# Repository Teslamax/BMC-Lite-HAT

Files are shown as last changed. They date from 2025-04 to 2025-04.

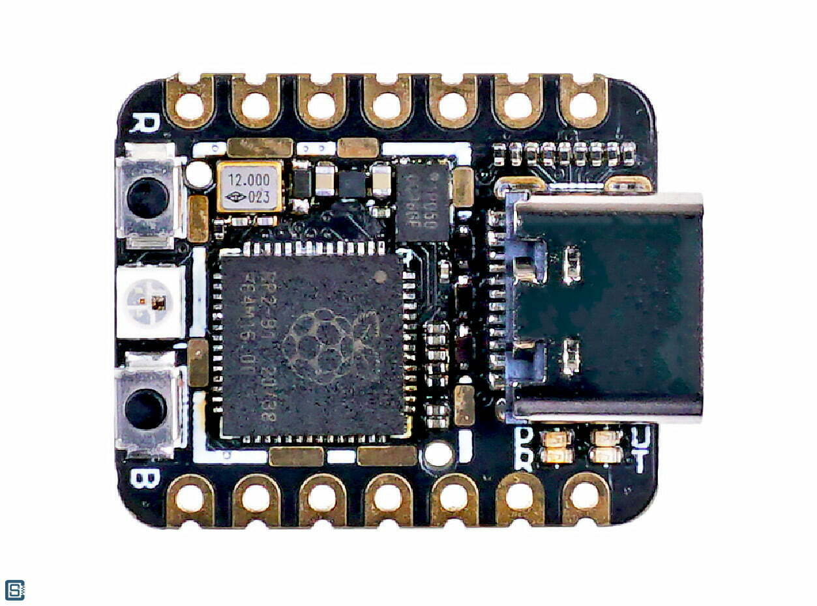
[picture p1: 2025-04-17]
hardware/XIAO RP2040/Seeedstudio-Seeeduino-XIAO-RP2040-Microcontroller-Board-PCB-Top-Shielding-Removed-1.jpg

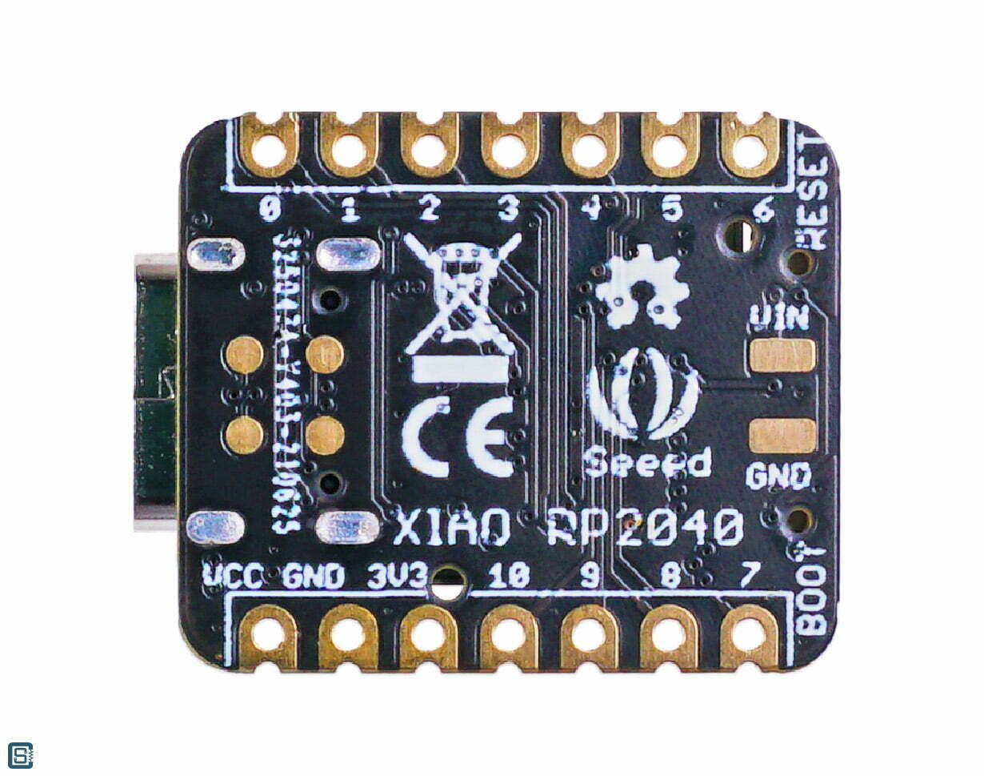
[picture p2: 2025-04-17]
hardware/XIAO RP2040/Seeedstudio-Seeeduino-XIAO-RP2040-Microcontroller-Board-PCB-Bottom-1.jpg

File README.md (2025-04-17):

# BMC-Lite HAT

A minimalist Raspberry Pi companion board that provides **safe power control**, **status indication**, and **serial console monitoring** for headless systems like the Pi Zero and Pi Zero 2.

BMC-Lite behaves like a simplified BMC (Baseboard Management Controller), using a microcontroller (e.g. XIAO RP2040) to coordinate shutdown, reboot, user-defined input, and status feedback — all with minimal Pi-side dependencies.

---

## ✨ Key Features

- 🧠 Clean shutdown, reboot, and optional user-defined buttons
- 🌈 RGB LED for system status (boot, running, halted, panic, etc.)
- 🔁 Bidirectional UART between Pi and MCU for serial console parsing
- 🫀 Heartbeat monitoring via `gpio-led` overlay on Pi GPIO6
- 🔌 Power-safe operation using Schottky diodes (no USB backfeed)
- 📟 Optional I²C OLED display (address `0x3C`)
- 📦 Compact Pi Zero-compatible form factor

---

## 🔩 Hardware Overview

- Microcontroller: **Seeed XIAO RP2040**
- Communication:
  - **UART** (Pi `GPIO14/15`) for console output / command reception
  - **GPIO overlays** for poweroff, shutdown, reboot
  - **I²C** (shared bus for OLED + optional MCP23017 expander)
- RGB LED: onboard XIAO NeoPixel used for state indication
- Buttons: physical momentary buttons (shutdown, reboot, user-defined)
- Power: 5V input from Pi via Schottky diode OR USB-C (dev mode)

> See [`OVERVIEW.md`](OVERVIEW.md) for detailed power modes and deployment strategy.

---

## ⚙️ Raspberry Pi Configuration

Add the following to your `/boot/config.txt`:

```ini
# Enable UART (optional but recommended)
enable_uart=1

# GPIO overlays
dtoverlay=gpio-shutdown,gpio_pin=22,active_low=1,gpio_pull=up
dtoverlay=gpio-poweroff,gpiopin=26,active_low=0
dtoverlay=gpio-restart,gpio_pin=27,active_low=1

# Heartbeat overlay (blinks GPIO6 at ~1Hz)
dtoverlay=gpio-led,gpio=6,trigger=heartbeat
```

> Note: Overlay pins can be adjusted if your board is wired differently — see [`docs/PINOUT.md`](docs/PINOUT.md).

---

## 🌈 RGB LED Status

| State | Color | Pattern | Meaning |
|---|---|---|---|
| Off | ⚫ Off | Off | No Pi power |
| Booting | 🟠 Orange  | Breathing | Pi serial console detected |
| Running | 🟢 Green | Solid | Heartbeat detected |
| Shutting Down | 🟡 Yellow  | Slow Blink | Shutdown in progress |
| Halted | 🔴 Red | Solid | GPIO26 HIGH — safe to power off  |
| Crash / Panic | 🟣 Magenta | Fast Blink | Kernel panic (detected via UART) |
| Unresponsive | 🟤 Amber | 2s Blink | Heartbeat timeout |

> A copy of this table also exists in the docs, alongside state machine definitions and implementation.

---

## 🧭 Pin Mapping

See [`docs/PINOUT.md`](docs/PINOUT.md) for the authoritative pin allocation between:

- Raspberry Pi GPIO
- XIAO RP2040
- Optional MCP23017 I/O Expander

---

## 📄 License

MIT or CC-BY 4.0 — TBD

---

## 💬 Credits

Designed by [You], with architectural support from ChatGPT.  
Inspired by system BMCs, IPMI, `systemd`, and the belief that small devices deserve great UX too.

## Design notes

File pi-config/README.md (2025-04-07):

# Raspberry Pi Setup Guide for BMC-Lite-HAT

This guide walks you through setting up your Raspberry Pi to work with the BMC-Lite HAT using GPIO overlays, UART, and the optional heartbeat monitoring service.

---

## 🧰 Files Included

- `config.txt.snippet`: Additions to your Pi's `/boot/config.txt`
- `cmdline.txt.snippet`: Serial console enable line for `/boot/cmdline.txt`
- `heartbeat.py`: Python script to toggle a GPIO as a heartbeat signal
- `heartbeat.service`: systemd unit file to run `heartbeat.py` at boot

---

## ⚙️ Step-by-Step Setup

### 1. Enable UART and Overlays

Edit your `/boot/config.txt`:

```bash
sudo nano /boot/config.txt
```

Append the following (or copy from `config.txt.snippet`):

```ini
enable_uart=1
dtoverlay=gpio-shutdown,gpio_pin=22,active_low=1,gpio_pull=up
dtoverlay=gpio-poweroff,gpiopin=26,active_low=0
dtoverlay=gpio-restart,gpio_pin=27,active_low=1
```

### 2. Enable Serial Console Output

Edit `/boot/cmdline.txt` (this file is a **single line**!):

```bash
sudo nano /boot/cmdline.txt
```

Add this to the end (if not present):

```
console=serial0,115200
```

> ⚠️ Do not break the line into multiple lines.

---

### 3. Install Heartbeat Service (Optional)

#### Copy files to their locations:

```bash
sudo cp pi-config/heartbeat/heartbeat.py /usr/local/bin/
sudo chmod +x /usr/local/bin/heartbeat.py
```

```bash
sudo cp pi-config/heartbeat/heartbeat.service /etc/systemd/system/
```

#### Enable the service:

```bash
sudo systemctl daemon-reexec
sudo systemctl enable heartbeat.service
sudo systemctl start heartbeat.service
```

To check status:

```bash
sudo systemctl status heartbeat.service
```

---

## 🔁 Reboot

After all steps are complete:

```bash
sudo reboot
```

Your Raspberry Pi should now:
- Output logs via UART
- Respond to shutdown/restart GPIOs
- Pulse GPIO17 as a heartbeat indicator

---

## ✅ Summary

- UART and overlays allow microcontroller monitoring and control
- Heartbeat helps detect unresponsive Pi
- No kernel modules or packages are required — just Python and systemd

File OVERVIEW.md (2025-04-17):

# BMC-Lite HAT – System Overview

BMC-Lite HAT is a compact Raspberry Pi companion board designed to provide basic BMC-like functionality such as controlled shutdown, reboot, user input, and visual feedback for headless systems.

Built around the Seeed XIAO RP2040, it integrates clean power handling, GPIO signaling, and serial monitoring in a Pi Zero-sized footprint.

## ✅ Key Capabilities

- Clean shutdown, reboot, and user interaction via physical buttons
- Visual feedback through onboard RGB LED (NeoPixel)
- Safe power sharing between Pi and USB using Schottky diodes
- DEV vs RUN mode switch for debugging vs deployment
- UART-based serial monitoring
- Optional I²C OLED and GPIO expander (MCP23017)

## 🔋 Power Notes

The XIAO RP2040 can be safely powered from either:

- The Raspberry Pi's 5V rail via an **external Schottky diode**
- Its onboard USB-C connection (protected by a built-in Schottky diode)

This allows safe simultaneous connection of both USB and Pi power without a physical DEV/RUN switch.
## 🔋 Power Architecture

- `V_SYS` rail is shared between Pi 5V (via diode) and USB-C
- XIAO VBUS (Pin 14) connects to V_SYS in RUN mode
- Schottky diodes prevent reverse current into Pi or USB host
## 🫀 Heartbeat Monitoring

To indicate the Pi is alive:

Add to `/boot/config.txt`:
```ini
dtoverlay=gpio-led,gpio=6,trigger=heartbeat
```

- Uses **GPIO6 (Pin 31)** to pulse at ~1Hz
- Connect to **XIAO GPIO10** or MCP23017 GPIO for monitoring
## 📦 Physical & Logical Summary

- Board form factor: pHAT (fits Pi Zero footprint)
- GPIO header: stacking or through-hole
- Optional 4-pin OLED header (`0x3C`)
- Optional MCP23017 I/O expander (`0x20`)

For detailed wiring, see [`docs/PINOUT.md`](docs/PINOUT.md)

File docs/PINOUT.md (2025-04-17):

# BMC-Lite HAT Pin Mapping

## 🔌 XIAO RP2040 GPIO Assignments

| GPIO | Pin | Function | Direction | Connected To | Notes |
|---|-----|---|---|---|---|
| 26 | 1 | `INT` from Expander | Input | *MCP23017* `INTA` Pin | INT fires on button state changes  |
| 27 | 2 | Free (`ADC1`) | — | — | General-purpose |
| 28 | 3 | Free (`ADC2`) | — | — | ADC-capable input |
| 29 | 4 | Free (`ADC3`) | — | — | ADC-capable input |
| 6 | 5 | I²C `SDA` | Bidirectional | OLED, GPIO Expander | Addr `0x3C` (OLED), `0x20` (MCP) |
| 7 | 6 | I²C `SCL` | Bidirectional | OLED, GPIO Expander | Shared I²C bus |
| 0 | 7 | UART `TX` | XIAO → Pi | Pi `GPIO15` (Pin 10)  | UART console |
| 1 | 8 | UART `RX` | Pi → XIAO | Pi `GPIO14` (Pin 8) | UART console |
| 2 | 9 | Free (`SPI`-`SCK`)  | — | — | — |
| 4 | 10  | `HEARTBEAT` | Input | Pi `GPIO6` (Pin 31) | `dtoverlay`-driven 1Hz pulse |
| 3 | 11  | Free (`SPI`-`MOSI`) | — | — | — |
| — | 12  | `3V3` | — | — | — |
| — | 13  | `GND` | — | — | — |
| — | 14  | `VBUS` | — | — | — |

---

## 🔌 MCP23017 GPIO Expander (Prototyping Phase) (I²C addr `0x20`)

| Bank | Pin| Function | Direction | Connected To | Notes |
|---|----|---|---|---|---|
| `GPB0` | 1  |  |  |  |  |
| `GPB1` | 2  |  |  |  |  |
| `GPB2` | 3  |  |  |  |  |
| `GPB3` | 4  |  |  |  |  |
| `GPB4` | 5  |  |  |  |  |
| `GPB5` | 6  |  |  |  |  |
| `GPB6` | 7  |  |  |  |  |
| `GPB7` | 8  |  |  |  |  |
| `VDD`  | 9  |  |  |  |  |
| `VSS`  | 10 |  |  |  |  |
| — | 11 |  |  |  |  |
| `SCL`  | 12 | I²C `SCL` | Bidirectional  |  XIAO `SCL` | Shared I²C bus |
| `SDA`  | 13 | I²C `SDA` | Bidirectional  |  XIAO `SDA` | Shared I²C bus |
| — | 14 |  |  |  |  |
| `A0` | 15 |  |  |  |  |
| `A1` | 16 |  |  |  |  |
| `A2` | 17 |  |  |  |  |
| `RST`  | 18 |  |  |  |  |
| `INTB` | 19 |  |  |  |  |
| `INTA` | 20 | Interrupt | Output | XIAO `GPIO26` (Pin 1) |  |
| `GPA0` | 21 | Shutdown button | Input | Shutdown button | Debounced in software  |
| `GPA1` | 22 | Reboot button | Input | Reboot button | Debounced in software  |
| `GPA2` | 23 | User button | Input | User button | Debounced in software  |
| `GPA3` | 24 | Poweroff-Ready | Input | | |
| `GPA4` | 25 | Signal safe halt | XIAO → Pi | Pi `GPIO17` | Logic state  |
| `GPA5` | 26 | Signal safe reboot | XIAO → Pi | Pi `GPIO27` | Logic state  |
| `GPA6` | 27 | Signal user-defined  | XIAO → Pi | Pi `GPIO22` | Logic state  |
| `GPA7` | 28 | Unused | — | — | Reserved for expansion |
| `GPB*` | —  | Unused | — | — | Reserved for expansion |

---

## 🔌 Raspberry Pi GPIO Assignments

| Pi GPIO | Pin | Function | Direction | Connected To | Notes |
|---|-----|---|---|---|---|
| 2 | 4 | 5V Power | Output | XIAO `VBUS` via diode | — |
| 14 | 8 | UART `TX` | Output | XIAO `RX` (`GPIO1`) | Serial console |
| 15 | 10  | UART `RX` | Input | XIAO `TX` (`GPIO0`) | Serial console |
| 17 | 11  | Shutdown Trigger | Input | Expander | `dtoverlay=gpio-shutdown` |
| 27 | 13  | Reboot Trigger | Input | Expander | `dtoverlay=gpio-restart` |
| 22 | 15  | User-defined Input | Input | Expander | Optional override or trigger |
| 5 | 29  | Poweroff-Ready | Output | Expander | High when safe to power off |
| 6 | 31  | `HEARTBEAT` | Output | XIAO `GPIO10` | dtoverlay: gpio-led trigger |

---

## 🔋 Power & Ground

| Signal | Pi Pin(s) | XIAO Pin | Notes |
|---|---|---|---|
| 5V | 2 or 4 | 14 (`VBUS`) | Via Schottky, dual-source capable — switch isolation no longer required |
| `GND`  | 6, 9, etc | 13 (`GND`)  | Shared ground reference |

> ⚠️ **Note on `VBUS` and Power Safety:**
>
> The XIAO RP2040 includes an internal Schottky diode between its USB-C VBUS input and Pin 14 (`VBUS`). This prevents backfeed from external 5V sources (like the Pi) into the USB port. When combined with an external Schottky diode protecting the Pi's 5V rail, this configuration allows safe, simultaneous connection of both USB-C and Pi 5V power **without requiring a physical DEV/RUN switch**. The XIAO RP2040 does not include a VBAT or battery charging circuit, so Seeed Studio's general battery safety warnings do not apply here.

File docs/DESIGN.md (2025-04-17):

# BMC-Lite HAT – Design Overview

**BMC-Lite HAT** is a compact, low-cost control and status interface board for headless Raspberry Pi systems.  
It provides **safe shutdown and reboot control**, **user input**, **status indication**, and **power protection**, while enabling easy prototyping and future expandability.

---

## 🎯 Project Goals

- Allow clean shutdown and reboot of headless Raspberry Pi devices
- Support up to 3 debounced physical buttons (shutdown, reboot, user)
- Monitor Pi health via UART and a heartbeat GPIO
- Provide visual feedback using the XIAO's onboard RGB LED and optional I²C OLED
- Maintain power separation and protection between the Pi and USB
- Fit entirely on a solderless breadboard for early prototyping

---

## 🧱 Hardware Overview

### MCU: **Seeed XIAO RP2040**

- Handles button input with debouncing
- Sends shutdown and reboot signals to the Pi
- Receives Pi "ready for poweroff" and "heartbeat" signals
- Optionally monitors UART output from Pi
- Drives an optional I²C OLED
- Uses all **12 GPIOs** on the XIAO

### Raspberry Pi

- Uses `dtoverlay`-based GPIO triggers
- Powered independently (no USB power sharing)
- Communicates with XIAO via GPIO and UART
- Provides power to XIAO (with diode protection)

---

## ⚡ Dual-Power Protection: Discrete Schottky Diodes

### Purpose:
Prevent power contention between **USB (VBUS)** and **Pi 3.3V rail** by OR-ing both into a common `V_SYS` rail.

### Materials:
- 1x discrete Schottky diodes (e.g., 1N5817, BAT85) (one is already protecting the USB-C 5v source on the XIAO-RP2040)
- 1x 10–47µF ceramic capacitor (0805/1206, X5R or X7R)

### Diagram:

```text
Pi 3.3V ───┬────|<|──┐
           │         │
           │         ├───► V_SYS ──► XIAO 3.3V (Pin 13)
USB 3.3V ──┴────|<|──┘
                 │
              [Capacitor]
                 │
                GND

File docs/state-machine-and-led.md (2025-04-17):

# BMC-Lite HAT – System State Machine and LED Status

This document defines the internal firmware state machine of the BMC-Lite HAT and its corresponding RGB LED feedback patterns. Together, these mechanisms enable real-time monitoring and intuitive diagnostics for headless Raspberry Pi systems.

---

## 🌈 LED Status Mapping

| State | Color | Behavior | Meaning |
|---|---|---|---|
| Off | ⚫ Off | Off | No Pi power |
| Booting | 🟠 Orange | Breathing | Parsing serial boot logs |
| Running | 🟢 Green | Solid | Heartbeat OK |
| Shutting Down | 🟡 Yellow | Slow Blink | Shutdown in progress |
| Halted | 🔴 Red | Solid | GPIO26 high: safe to power off |
| Crash / Panic | 🟣 Magenta | Fast Blink | Kernel panic, log detected |
| Unresponsive | 🟤 Amber | 2s Blink | Heartbeat timeout |

---

### State Descriptions

- **OFF**: No Pi power (5V not detected)
- **BOOTING**: Serial console active, parsing boot messages
- **RUNNING**: Heartbeat GPIO detected, Pi is healthy
- **SHUTTING_DOWN**: Serial message indicates shutdown
- **UNRESPONSIVE**: Heartbeat GPIO silent (timeout)
- **CRASHED**: Kernel panic or failure detected in serial output
- **HALTED**: GPIO26 pulled HIGH via dtoverlay = safe to power off
- **OVERRIDE**: User override state, for testing or forcing modes

## 🧠 System State Machine

```mermaid
stateDiagram-v2
    [*] --> OFF
    OFF --> BOOTING : Pi 5V detected
    BOOTING --> RUNNING : boot log
    BOOTING --> CRASHED : panic log
    RUNNING --> SHUTTING_DOWN : shutdown log
    RUNNING --> UNRESPONSIVE : heartbeat timeout
    SHUTTING_DOWN --> HALTED : GPIO26 HIGH
    UNRESPONSIVE --> HALTED : GPIO26 HIGH
    CRASHED --> HALTED : GPIO26 HIGH

    OFF --> OVERRIDE : manual
    RUNNING --> OVERRIDE : manual
    OVERRIDE --> RUNNING : exit override
    OVERRIDE --> BOOTING : simulate boot

    note right of OVERRIDE
      Manual override mode
      used for testing or simulation
    end note
```

---

## 📝 Notes

- LED color mappings follow conventional metaphors (red = stop, green = go).
- LED behavior is configurable in firmware: blink rate, colors, animations.
- OVERRIDE state can manually trigger test LEDs or simulate boot/poweroff sequences.
- System transitions may also be logged via USB CDC or Telnet CLI (if enabled).

---

## 📚 Related

- [`WIRING.md`](WIRING.md) for heartbeat GPIO and LED wiring
- [`POWER.md`](POWER.md) for power detection behavior

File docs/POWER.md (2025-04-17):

# BMC-Lite HAT – Power Architecture & Safety

This document describes how power flows through the BMC-Lite HAT system and explains the use of diodes to safely support both Raspberry Pi and USB power sources.

---

## 🔋 Overview

The system is designed to allow the Raspberry Pi and USB-C to be connected at the same time without risk of damaging backfeed.

### Power Sources:
- **USB-C** → XIAO RP2040 (internal Schottky protection)
- **Raspberry Pi 5V GPIO (Pin 2 or 4)** → external Schottky diode → XIAO VIN

Both sources feed into a common `V_SYS` rail safely.

---

## 🔌 Diode-Based Protection

### XIAO RP2040 (Built-in):
- Includes a **Schottky diode** from USB-C to VBUS (Pin 14)
- Prevents backfeed from Pi into USB host

### Raspberry Pi to XIAO (External):
- A **1N5819** or similar diode is placed between the Pi’s 5V rail and the XIAO’s VBUS
- Prevents USB power from backfeeding into the Pi

---

## 🔄 Power Flow Diagram (Textual)

```
[Pi 5V GPIO] --|>|--+
               D1   |
                   [ V_SYS Rail ] --- XIAO VBUS (Pin 14)
[USB-C] --------|>|--+
               (internal)
```

> **D1**: External Schottky diode (e.g., 1N5817, SS14, BAT54)

---

## ✅ Safe Use Cases

| Power Scenario | Safe? | Notes |
|---|---|---|
| Only Pi connected (no USB) | ✅ | Pi powers XIAO through D1 |
| Only USB connected | ✅ | USB powers XIAO via internal diode |
| Both connected | ✅ | Each input is isolated; no current conflict  |

---

## ⚠️ Best Practices

- Use **low forward-voltage Schottky diodes** for efficient power transfer
- Place a **47–100 µF capacitor** near VIN and GND to smooth transitions
- No need for a physical switch — diode logic handles source selection

---

## 🧪 Development Notes

- If powering from USB only, the Pi can be safely unplugged or powered off
- For final deployment, USB can be used for data/firmware only, not power

---

## 📚 See Also

- [`WIRING.md`](WIRING.md) for breadboard wiring
- [`PINOUT.md`](PINOUT.md) for power pin locations

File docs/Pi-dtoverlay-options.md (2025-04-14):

On Raspberry Pi OS, `dtoverlay=` entries in `/boot/config.txt` use **device tree overlays** to configure hardware behavior—this includes assigning GPIO pins special functions like shutdown, UART, I²C, etc.

Here's a **comprehensive list of common GPIO-related overlays** you can use, with descriptions and usage examples.

---

## 🔌 Common GPIO-related `dtoverlay=` Presets

| Overlay | Purpose | Default GPIO | Example |
|---|---|---|---|
| `gpio-shutdown` | Shutdown on button press | GPIO 3 | `dtoverlay=gpio-shutdown` |
| `gpio-restart` | Reboot on button press | GPIO 3 | `dtoverlay=gpio-restart` |
| `gpio-poweroff` | Set GPIO high or low on shutdown | GPIO 26 | `dtoverlay=gpio-poweroff,gpiopin=26,active_low=1` |
| `gpio-fan` | Turn fan on/off based on temp | GPIO 14 | `dtoverlay=gpio-fan,gpiopin=14,temp=55000` |
| `gpio-key` | Emulate keypress on GPIO event | (custom) | `dtoverlay=gpio-key,gpio=17,keycode=116,label=power` |
| `i2c-gpio` | Create I²C interface on arbitrary GPIOs | GPIO 23/24 | `dtoverlay=i2c-gpio,i2c_gpio_sda=23,i2c_gpio_scl=24` |
| `spi-gpio` | Create SPI interface on arbitrary GPIOs | (custom) | `dtoverlay=spi-gpio,mosi=20,miso=19,sclk=21,cs0=18` |
| `uart-gpio` | Create UART on arbitrary GPIOs | (custom) | `dtoverlay=uart-gpio,gpio_tx=14,gpio_rx=15` |
| `pi3-act-led` | Redirect ACT LED to GPIO | GPIO 47 (Pi 3 only) | `dtoverlay=pi3-act-led,gpio=18` |
| `pi3-disable-bt` | Disable Bluetooth to free UART | - | `dtoverlay=pi3-disable-bt` |
| `pi3-miniuart-bt` | Use mini UART for BT, free full UART | - | `dtoverlay=pi3-miniuart-bt` |

---

## 🔄 Details for Key Overlays

### 🔹 `gpio-shutdown`
- Triggers **safe shutdown** when GPIO is pulled low
- Optional parameters:
  - `gpio_pin` (default: 3)
  - `active_low=1` or `0` (polarity)
  - `gpio_pull=up/down/none`

```ini
dtoverlay=gpio-shutdown,gpio_pin=17,active_low=1
```

---

### 🔹 `gpio-restart`
- Triggers **safe reboot** when GPIO is pulled low
- Default: GPIO 3
- Parameters:
  - `gpio_pin`
  - `active_low`
  - `gpio_pull`

```ini
dtoverlay=gpio-restart,gpio_pin=27
```

---

### 🔹 `gpio-poweroff`
- Drives a GPIO **high or low after halt**, useful to **cut external power**
- Optional parameters:
  - `gpiopin` (default: 26)
  - `active_low=0|1` (whether "on" is high or low)
  - `input=0|1` (input mode)
  - `export=0|1` (export to sysfs)

```ini
dtoverlay=gpio-poweroff,gpiopin=22,active_low=1
```

---

### 🔹 `gpio-fan`
- Turns a GPIO-controlled fan on/off based on temp threshold
- Parameters:
  - `gpiopin`
  - `temp` (in millidegrees C)

```ini
dtoverlay=gpio-fan,gpiopin=18,temp=60000
```

---

### 🔹 `gpio-key`
- Emulates **Linux key events** from GPIO presses
- Useful for adding volume or power buttons
- Parameters:
  - `gpio`
  - `keycode` (Linux input keycode)
  - `label` (descriptive name)

```ini
dtoverlay=gpio-key,gpio=17,keycode=116,label=power
```

---

## 📚 Discover Available Overlays

To list all available overlays on your system:
```bash
ls /boot/overlays/
```

To view available parameters for a specific overlay:
```bash
sudo dtoverlay -h gpio-shutdown
```

---

## ⚠️ Notes
- Some GPIOs are used at boot time (e.g., I²C, SPI, UART), be cautious when overriding them.
- `gpio=3` (physical pin 5) is shared with I²C SDA, so using it for `shutdown`/`restart` may conflict with I²C.

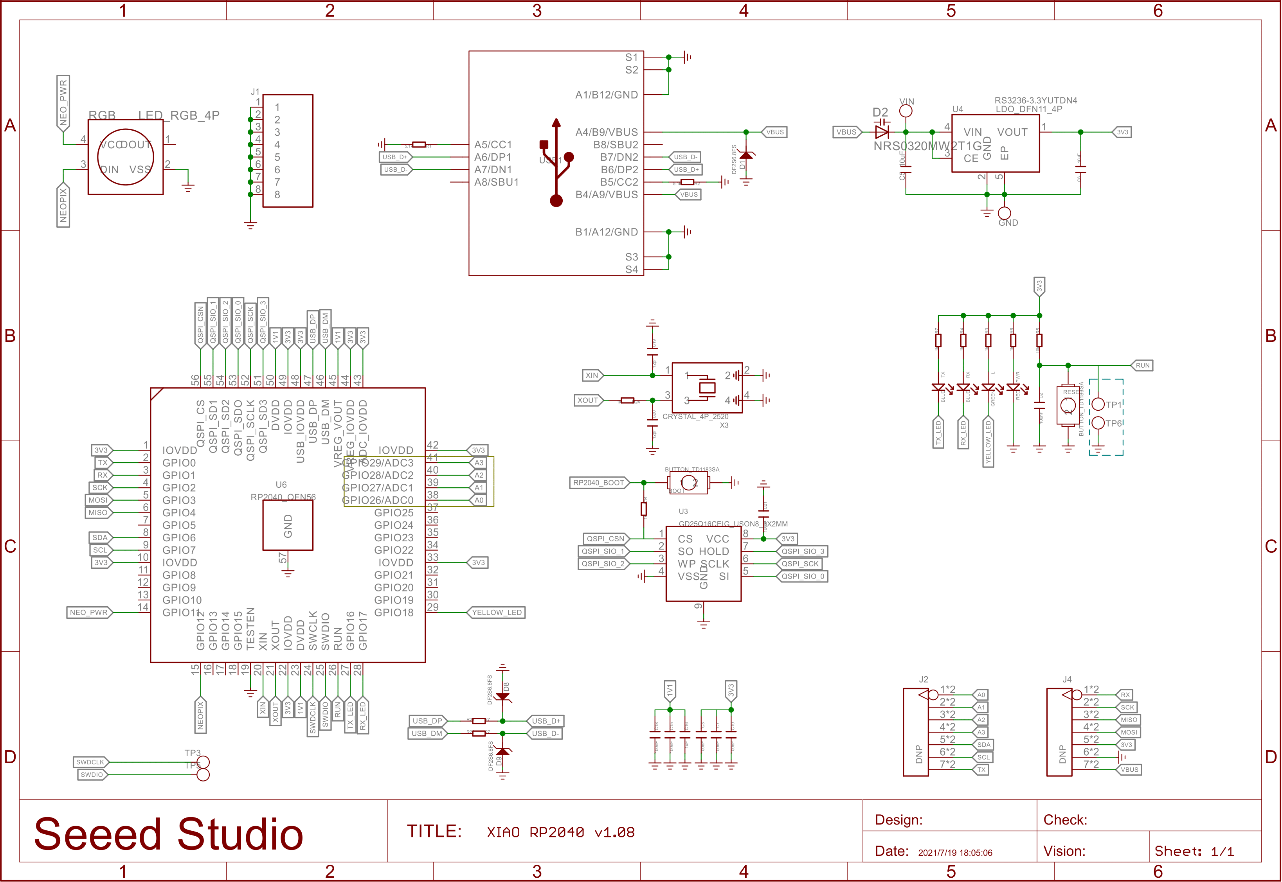
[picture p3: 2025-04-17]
hardware/XIAO RP2040/Seeedstudio-Seeeduino-XIAO-RP2040-Microcontroller-Board-Schematic-1.png

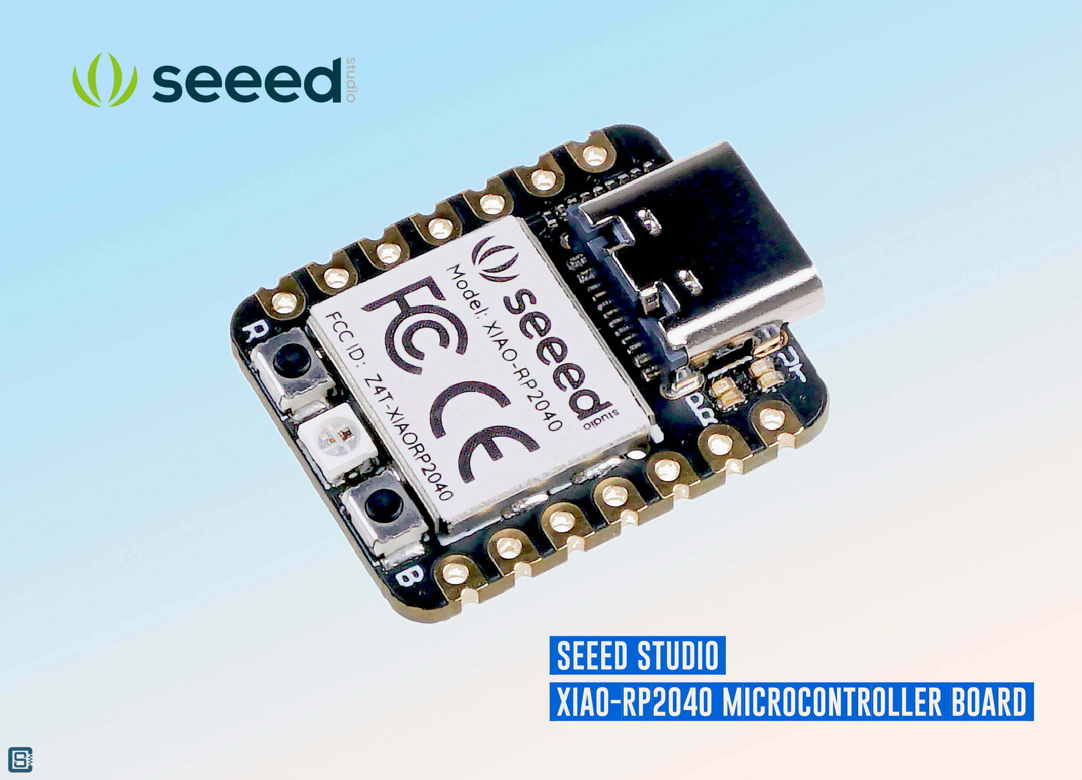
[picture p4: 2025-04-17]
hardware/XIAO RP2040/Seeedstudio-Seeeduino-XIAO-RP2040-Microcontroller-Board-CIRCUITSTATE-Featured-Image-1_2.jpg

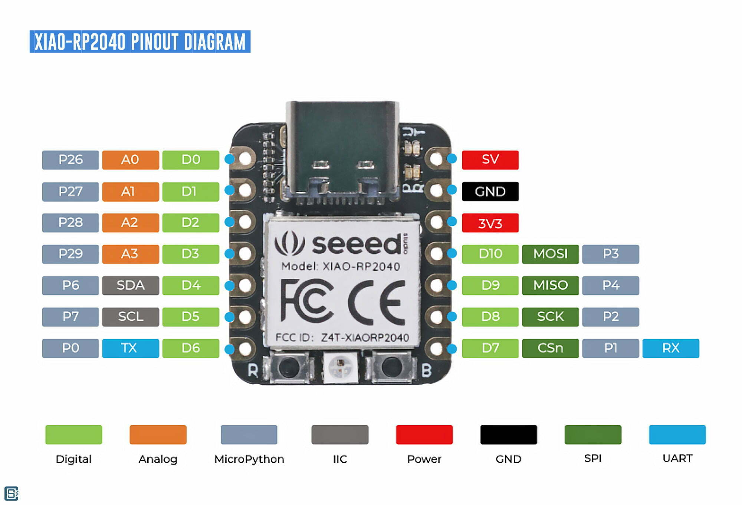
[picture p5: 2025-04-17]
hardware/XIAO RP2040/Seeedstudio-Seeeduino-XIAO-RP2040-Microcontroller-Board-Pinout-Diagram-1.jpg

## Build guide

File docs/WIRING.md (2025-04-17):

# BMC-Lite HAT – Breadboard Wiring Guide

This guide describes the practical breadboard and prototyping wiring for the BMC-Lite HAT system using the Seeed XIAO RP2040 and a Raspberry Pi.

---

## 🧰 Components

- 1× **Seeed Studio XIAO RP2040** (with onboard RGB NeoPixel)
- 3× Momentary pushbuttons: `SHUTDOWN`, `REBOOT`, `USER1`
- 1× **1N5819** (or similar Schottky diode) for Pi 5V → XIAO VIN
- 1× **100 µF electrolytic capacitor** (power smoothing)
- Jumper wires, breadboard, headers
- *(Optional)* I²C OLED (addr `0x3C`)
- *(Optional)* MCP23017 GPIO expander (addr `0x20`)

---

## 🔌 Power Wiring

- **Pi 5V GPIO** → 1N5819 diode → **XIAO VIN (Pin 14)**
- **XIAO GND** ↔ **Pi GND** (any shared ground pin)
- Place 47–100 µF capacitor across **VIN and GND** on the XIAO

> USB-C can be connected at the same time for programming/debug — both USB and Pi 5V lines are protected via Schottky diodes.

---

## 🔘 Button Wiring (Direct to XIAO GPIOs)

Use internal pull-ups or 10kΩ external pull-ups to 3.3V.  
Place a 0.1 µF capacitor across each button for basic hardware debounce.

| Button | XIAO GPIO | Pin  |
|---|---|---|
| Shutdown | GPIO0 | 7 |
| Reboot | GPIO1 | 8 |
| User | GPIO2 | 9 |

---

## 🔁 UART Wiring

- **Pi TX (GPIO14, Pin 8)** → **XIAO RX (GPIO1, Pin 8)**
- **XIAO TX (GPIO0, Pin 7)** → **Pi RX (GPIO15, Pin 10)**

---

## 🫀 Heartbeat Wiring

- Pi GPIO6 (Pin 31) is configured with `dtoverlay=gpio-led`
- Wire this to XIAO GPIO4 (Pin 10)

---

## ⚙️ Pi Configuration Snippet

In `/boot/config.txt`:

```ini
enable_uart=1

dtoverlay=gpio-shutdown,gpio_pin=22,active_low=1,gpio_pull=up
dtoverlay=gpio-poweroff,gpiopin=26,active_low=0
dtoverlay=gpio-restart,gpio_pin=27,active_low=1
dtoverlay=gpio-led,gpio=6,trigger=heartbeat
```

---

## 💡 RGB LED Behavior

The onboard NeoPixel is used for state feedback.

| State | Color | Pattern | Meaning |
|---|---|---|---|
| Booting | 🟠 Orange  | Breathing | Serial output detected |
| Running | 🟢 Green | Solid | Heartbeat received |
| Shutting Down | 🟡 Yellow  | Slow Blink | Shutdown in progress |
| Halted | 🔴 Red | Solid | Poweroff signal detected |
| Crash / Panic | 🟣 Magenta | Fast Blink | Kernel panic via UART |
| Unresponsive | 🟤 Amber | 2s Blink | Heartbeat lost |

---

## 📌 Notes

- For more advanced I/O (buttons via expander), see [`docs/PINOUT.md`](PINOUT.md)
- For board-level wiring or KiCad files, see the main project files or future releases

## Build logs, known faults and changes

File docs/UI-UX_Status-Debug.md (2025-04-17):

## BMC Lite HAT Status & Debug Interface

This document describes the three primary status/debug channels on the BMC Lite HAT: **USB‑CDC (Serial)**, **On‑Board SSD1306 OLED**, and **Discrete R/G/B LEDs**, along with the logging levels, UI/UX conventions, and console commands available to developers and end‑users.

---

### 1. USB‑CDC (Serial) Channel

#### Purpose
- Full‑verbosity logging for development and field diagnostics.
- Command interface for runtime configuration (e.g. log levels, echo control).

#### Logging Levels & Prefixes
| Level | Macro | Prefix  | Description |
|---|---|---|---|
| Error | `logError` | ❌ | Fatal errors — halt or recoverable |
| Warn | `logWarn` | ⚠️ | Warnings — recoverable issues |
| Info | `logInfo` | ℹ️ | General status updates |
| Verbose | `logVerbose` | 🔍 | Detailed debug / trace messages |

- **Runtime level** controlled by `cdcLogLevel` (0–3).
- **Change** via console:
  ```
  /loglevel <0|1|2|3>   # set verbosity
  ```

#### Console Commands
- `/echo on` / `/echo off`  → enable/disable per‑line user echo
- `/loglevel N`             → set CDC verbosity (0=errors…3=all)
- Custom: `/i2cscan`, `/showheap`, `/reset`

#### Firmware Echo & Pi‑UART Relay
- **Firmware Echo**
  - Controlled by compile‑time macro `ECHO_USER_INITIAL` (default on/off) and runtime commands `/echo on` / `/echo off`.
  - When enabled, each user‑entered line is echoed back over CDC *once per line* and prefixed with `ECHO_USER_PREFIX` (e.g. "➡️ ").
- **Pi UART Relay**
  - All data received on the Pi’s UART (`Serial1`) is forwarded over USB‑CDC and prefixed *once per line* with `PI_ECHO_PREFIX` (e.g. "🐧 ") to distinguish Pi‑originated text from firmware logs.

---

### 2. On‑Board SSD1306 OLED (Blue)

#### Purpose
- Contextual, menu‑driven status display.
- Transient pop‑ups for errors or user actions.

#### UI Layout
```
╔════════════════════════╗
║ State: <STATE_NAME>    ║  ← line 1: current system state
║ Last Cmd: <text…>      ║  ← line 2: last console command
║ I2C: 0x3C,0x20 OK      ║  ← line 3: bus health
║ Uptime: 12s | Heap: 42K║  ← line 4: stats
╚════════════════════════╝
```

- **Transient Alerts:** overlay full screen for 1–2 s on errors.
- **Menu Mode:** use `USER1`/`SHUTDOWN` as up/down, `REBOOT` as Enter:
  ```
  • LogLevel: 2
    I2C Scan
    Reboot
  ```

---

### 3. Discrete R/G/B LEDs (GP17, GP16, GP25)

#### Purpose
- Immediate, glanceable indicators of bus & console activity.

| LED | Pin | Function | Behavior |
|---|---|---|---|
| Red | GP17  | USB‑CDC → Pi (TX) | 2 ms pulse on each byte sent from PC to Pi |
| Green | GP16  | Pi → USB‑CDC (RX) | 2 ms pulse on each byte received from Pi |
| Blue | GP25  | CDC / I2C idle/active | Soft blink while any activity present; OFF when idle |

- **Pulse Width:** ~2 ms (adjustable)
- **Blink Rate:** ~200 ms toggle to indicate continuous activity

---

### Integration in `parseUART()`
```cpp
void parseUART() {
  // Pi→USB (Green)
  while (Serial1.available()) {
    pulseLED(LED_GREEN_PIN);
    // relay + prefix…
  }
  // USB→Pi (Red)
  while (Serial.available()) {
    pulseLED(LED_RED_PIN);
    // forward + optional echo…
  }
  // Activity LED (Blue)
  updateActivityLED();
}
```

---

### Summary of Console GUI/UX
1. **Verbose development:** monitor CDC at max log level with Serial Monitor.
2. **Glance diagnostics:** built‑in RGB LED shows real‑time bus & console traffic.
3. **Contextual info:** OLED offers state, metrics, and a simple menu for configuration.
4. **Commands:** `/echo`, `/loglevel`, plus custom utilities (`/i2cscan`, `/heap`, `/reboot`).

By combining these channels, you gain layered visibility: **complete logs** on CDC, **one‑look** status on LEDs, and **context menus** on the OLED, ensuring both rapid development and clear end‑user feedback.

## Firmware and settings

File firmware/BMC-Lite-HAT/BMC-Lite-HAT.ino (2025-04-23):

//#include "src/main.cpp"

#include <Arduino.h>
#include <Wire.h>
#include <Adafruit_MCP23X17.h>

#include "src/uart_parser.h"
#include "src/oled.h"
#include "src/buttons.h"

//#include "src/config.h"
//#include "pinmap.h"
//#include "status_led.h"
//#include "debug.h"

//Adafruit_MCP23X17 mcp;

void setup() {
  initSerialInterfaces();
  Wire.begin();            // uses GP6/GP7 by default on the XIAO

  initStatusLED();

/*
  // what was this again?
  pinMode(LED_RED_PIN, OUTPUT);
  pinMode(LED_GREEN_PIN, OUTPUT);
  pinMode(LED_BLUE_PIN, OUTPUT);
  digitalWrite(LED_RED_PIN, LOW);
  digitalWrite(LED_GREEN_PIN, LOW);
  digitalWrite(LED_BLUE_PIN, LOW);
*/

  initButtons();

  initUARTParser();
  setSystemState(STATE_BOOTING);

  initDisplay();
  drawButtonStatus();

  drawHUD();  // Initial screen
}



void loop() {
  parseUART();
  updateStatusLED();
  updateCdcActivityLED();
  checkButtons();

/*
  Serial.print("GPA0: ");
  Serial.print(mcp.digitalRead(0));
  Serial.print(" | GPA1: ");
  Serial.print(mcp.digitalRead(1));
  Serial.print(" | GPA2: ");
  Serial.println(mcp.digitalRead(2));
  delay(250);  // slow down for readability
*/

}






/*
#include <Arduino.h>
#include <Wire.h>

#include "pinmap.h"
#include "status_led.h"
#include "uart_parser.h"
#include "buttons.h"

void setup() {
  Serial.begin(115200);        // USB‑CDC
  while (!Serial);

  Serial1.begin(115200);       // UART0 on GP0/GP1
  Wire.begin();

  initStatusLED();
  initButtons();
  initUARTParser();

  setSystemState(STATE_BOOTING);
}

void loop() {
  parseUART();             // does both relay + parsing + echo
  updateStatusLED();
  checkButtons();
}
*/

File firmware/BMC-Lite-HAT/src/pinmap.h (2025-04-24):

#pragma once

#include <Arduino.h>

// ─────────────────────────────────────────────
// XIAO RP2040 Physical Pinout (Castellated I/O)
// ─────────────────────────────────────────────

// I2C Bus
#define PIN_I2C_SDA            6   // GPIO 6 (D6)
#define PIN_I2C_SCL            7   // GPIO 7 (D7)

// UART to Pi
#define PIN_UART_TX            0   // GPIO 0 (D0)
#define PIN_UART_RX            1   // GPIO 1 (D1)

// NeoPixel (onboard)
#define NEOPIXEL_DATA_PIN      12  // GPIO 12 (D12)
#define NEOPIXEL_POWER_PIN     11  // GPIO 11 (D11)

// Built-in RGB LED indicators
#define LED_RED_PIN            17  // GPIO 17 — USB→Pi TX activity
#define LED_GREEN_PIN          16  // GPIO 16 — Pi→USB RX activity
#define LED_BLUE_PIN           25  // GPIO 25 — CDC activity/idle

// HEARTBEAT signal input from Pi (fast pulse)
#define PIN_HEARTBEAT_INPUT    10  // GPIO 10 — direct input from Pi (no debounce)

// Optional test/debug pins
#define DEBUG_PIN_0            2   // GPIO 2 (D2)
#define DEBUG_PIN_1            3   // GPIO 3 (D3)
#define DEBUG_PIN_2            4   // GPIO 4 (D4)
#define DEBUG_PIN_3            5   // GPIO 5 (D5)
#define DEBUG_PIN_4            8   // GPIO 8 (D8)
#define DEBUG_PIN_5            9   // GPIO 9 (D9)

// ─────────────────────────────────────────────
// I/O Function Mapping Summary
// ─────────────────────────────────────────────
// | Signal Name           | Direction | Source         | Description
// |------------------------|-----------|----------------|-----------------------------
// | PIN_I2C_SDA            | I/O       | XIAO GPIO 6    | I²C Data line
// | PIN_I2C_SCL            | O         | XIAO GPIO 7    | I²C Clock line
// | PIN_UART_TX            | O         | XIAO GPIO 0    | UART TX → Pi RX
// | PIN_UART_RX            | I         | XIAO GPIO 1    | UART RX ← Pi TX
// | NEOPIXEL_DATA_PIN      | O         | XIAO GPIO 12   | WS2812 NeoPixel data
// | NEOPIXEL_POWER_PIN     | O         | XIAO GPIO 11   | Power enable for NeoPixel
// | LED_RED_PIN            | O         | XIAO GPIO 17   | TX activity indicator
// | LED_GREEN_PIN          | O         | XIAO GPIO 16   | RX activity indicator
// | LED_BLUE_PIN           | O         | XIAO GPIO 25   | USB/CDC activity indicator
// | PIN_HEARTBEAT_INPUT    | I         | XIAO GPIO 10   | Pulse from Pi (fast)
// | DEBUG_PIN_*            | I/O       | XIAO GPIO 2–9  | Debug/expansion testpoints
// | EXP_BUTTON_RAW_*       | I         | MCP23017       | Raw expander button inputs
// | EXP_SIGNAL_*           | Logic     | Firmware       | Debounced button states
// | EXP_LED_POWEROFF       | I         | MCP23017       | Power-off status LED

// ─────────────────────────────────────────────
// MCP23017 I/O Expander Virtual GPIO Mapping
// ─────────────────────────────────────────────

// Raw button input pins (un-debounced)
#define EXP_BUTTON_RAW_SHUTDOWN 0   // GPA0
#define EXP_BUTTON_RAW_REBOOT   1   // GPA1
#define EXP_BUTTON_RAW_USER1    2   // GPA2

// LEDs controlled via expander  (RED: safe to remove power)
#define EXP_LED_POWEROFF_RAW    3   // GPA3 → MCP23017-DIP pin 24 → breadboard row 33/E
// MCP23017.GPA3 (pin 24) → Pi.GPIO5 (pin 29) 

// Debounced logical state (used by firmware)
#define EXP_GPIO_SIG_SHUTDOWN   4   // GPA4
#define EXP_GPIO_SIG_REBOOT     5   // GPA5
#define EXP_GPIO_SIG_USER1      6   // GPA6

//#define EXP_LED_USER_MODE      9  // Optional user-defined status LED

// ─────────────────────────────────────────────
// I2C Device Addresses
// ─────────────────────────────────────────────
#define MCP23017_I2C_ADDR      0x20
#define OLED_I2C_ADDR          0x3C

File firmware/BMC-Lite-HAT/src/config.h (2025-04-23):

#pragma once

#define FIRMWARE_VERSION "0-b1 (dev)"

// ———————————————————————————————
// User‑echo compile‑time defaults
#define ECHO_USER_INITIAL  true
#define ECHO_USER_PREFIX   "➡️ "
#define PI_ECHO_PREFIX     "🐧 "

// ————— CDC Log‑Level Prefixes —————
#define CDC_INFO_PREFIX    "ℹ️  "   // informational
#define CDC_WARN_PREFIX    "⚠️  "   // warnings
#define CDC_ERROR_PREFIX   "❌ "    // errors
#define CDC_VERBOSE_PREFIX "🔍 "   // verbose/debug

// Set your runtime verbosity (0=errors only, 1=warnings+errors, 2=info+warn+err, 3=all)
static uint8_t cdcLogLevel = 2;
// ———————————————————————————————

// ─────────────────────────────────────────────
// Serial Configuration Defaults
// ─────────────────────────────────────────────
#define UART1_BAUDRATE         115200
#define UART1_DATABITS         8
#define UART1_PARITY           SERIAL_8N1  // Arduino style: SERIAL_8N1, SERIAL_7E1, etc.
#define UART1_TIMEOUT_MS       100         // Optional read timeout (not always used)

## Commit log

2025-04-07 Add ChatGPT-assisted proposal.
    [bmc-lite-hat.sch, config.txt]
2025-04-07 Add IDE scaffolding.
    [bmc-lite-hat.kicad_pcb, bmc-lite-hat.kicad_sch, bom.csv]
2025-04-11 Update and rename gpio_mapping.md to Wiring-Schematic.md
2025-04-11 Add ChatGPT's Gritzing & KiCad files
2025-04-11 Update KiCad from Haruna
    [bmc-lite-hat.kicad_sch]
2025-04-17 Updated KiCad schematic & Arduino IDE files
2025-04-17 Update hardware files
    [bmc-lite-hat.kicad_sch]
2025-04-23 Update code from Haruna - button logic working
